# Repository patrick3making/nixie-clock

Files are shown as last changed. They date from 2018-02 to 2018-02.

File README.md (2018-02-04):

# nixie-clock
This alternative clock imitates a nixie tube by edge lighting acrylic tiles. The number on the tile indicates the current hour, and the color aproximately incates the minute.  
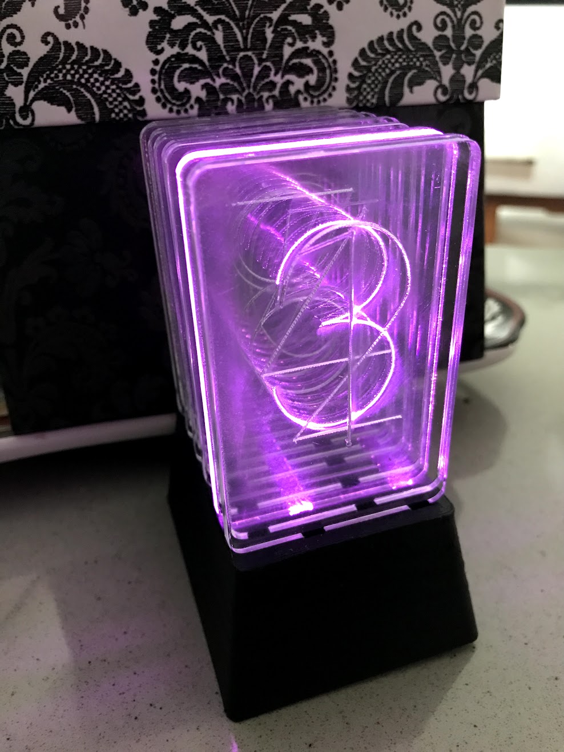
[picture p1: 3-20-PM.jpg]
  
  
## Background  
I have access to a laser cutter at work and I wanted to use it. I searched thingiverse and found [this single led nixie digit ](https://www.thingiverse.com/thing:880429). I modified and laser cut the tiles from that design. The base and circuit assembly is my design.  
  
# Construction
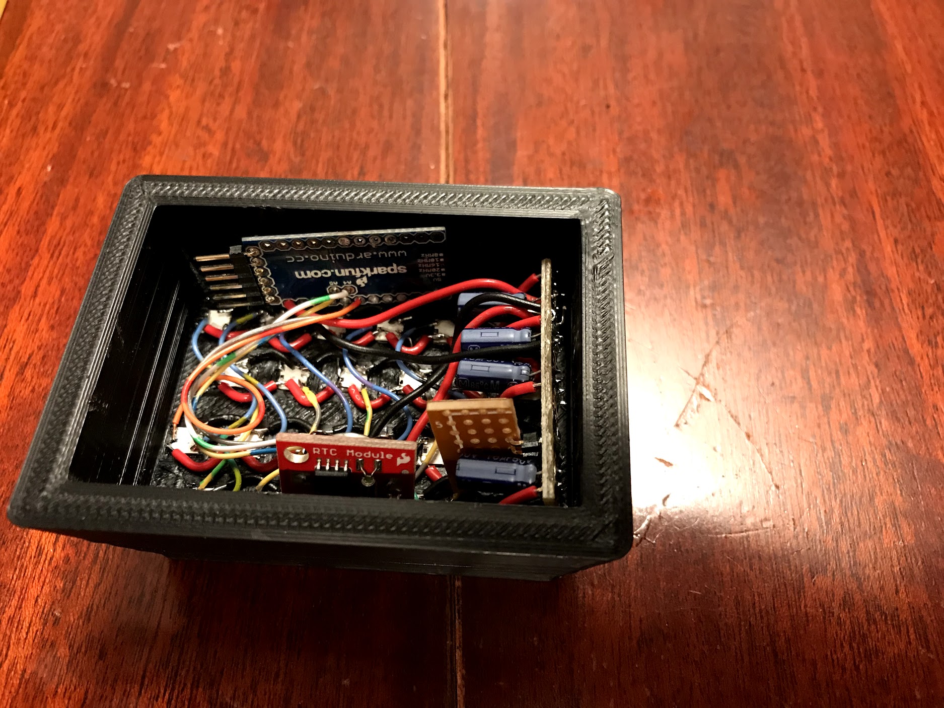
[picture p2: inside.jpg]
  
## Electronics
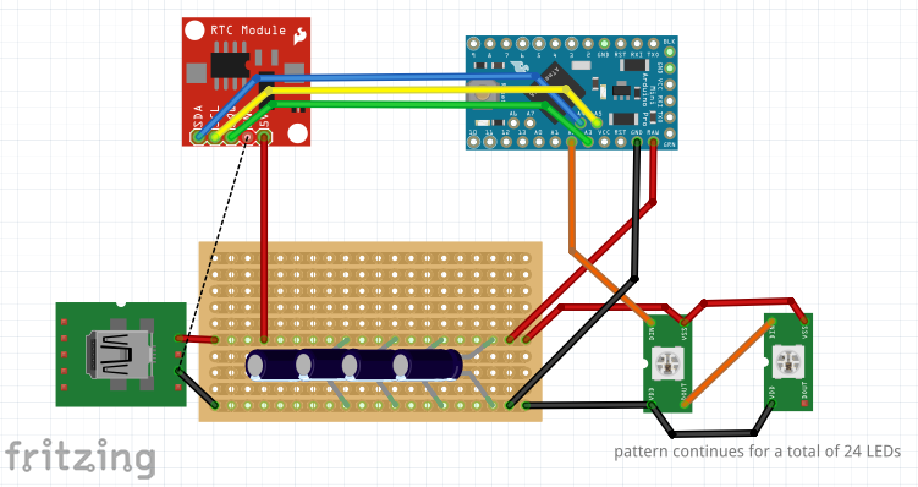
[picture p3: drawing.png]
circuit drawing
  
The electronics are controlled by an [Arduino Pro Mini](https://sfe.i0/p11113). Time is kept by a [SparkFun RTC Module](https://sfe.io/p12708). Light is provided by some [loose WS2812](https://sfe.io/p13667)s. That LED requires some decoupling, so I soldered the power connections together in four rows and added 10uf capacitors at the beginning of each row. It's not ideal, but the seem to work well.  
Power is provided through a USB connector I stole from a broken dev board. Since this runs on 5 volts, USB provides what I need and helps me use up a pile of old cables that might otherwise end up in the trash.  
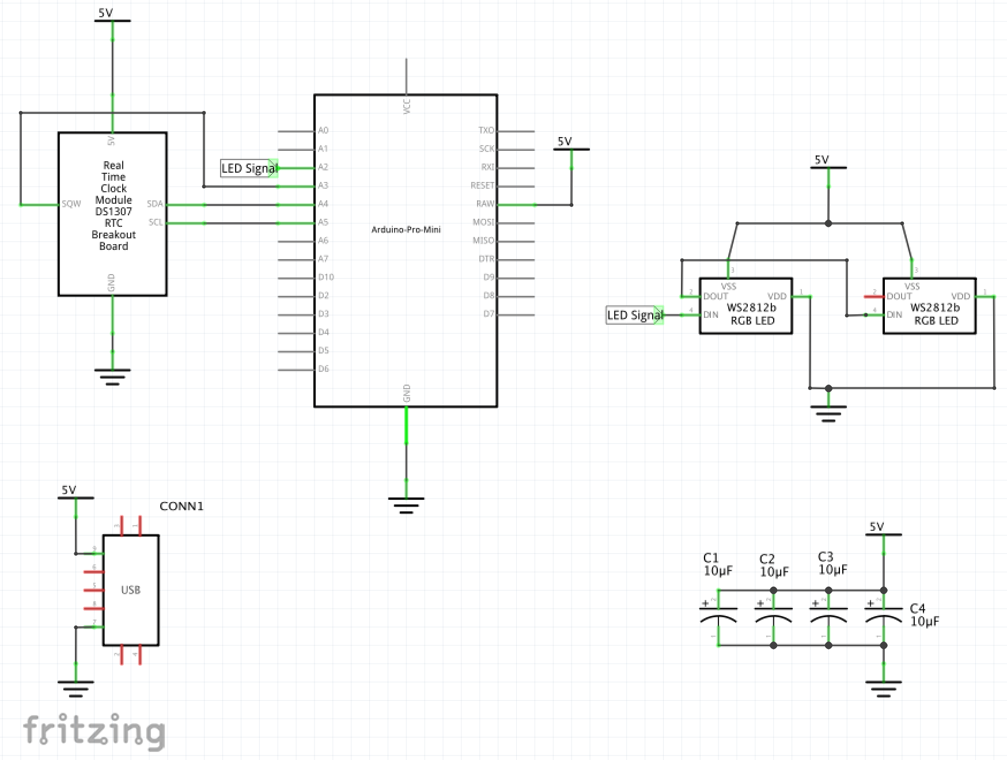
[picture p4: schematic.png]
circuit diagram
  
  
## Base  
The base has holes for the teeth of each tile that fit just right. The array of holes is staggered very close to right, but there is some error from one tile to the next. The space undneath has square holes for the LEDs. The bottom cavity is 1 inch deep because I wanted plenty of room for the electronics.  
  
## Assembly
The best way to do this project is make a custom pcb for the LEDs and controls. In lieu of doing it correctly, I spent immensely greater time and effort putting tiny wires between tiny smd components.  
**Recommendation**: If you make this, redesign the base for [through hole WS2812](https://sfe.io/p12999)s. That will make the soldering easier, and those long leads will save SO MUCH wire stripping.  
After 3D printing the base, I super-glued the LEDs into their sockets. Next I soldered about 100 wires, most of which were less than an inch long. They came from an old 25-pair telephone cable. It makes great hookup wire because it's solid core copper and it's not twisted like cat 5. Power is distributed across a piece of prototyping board.

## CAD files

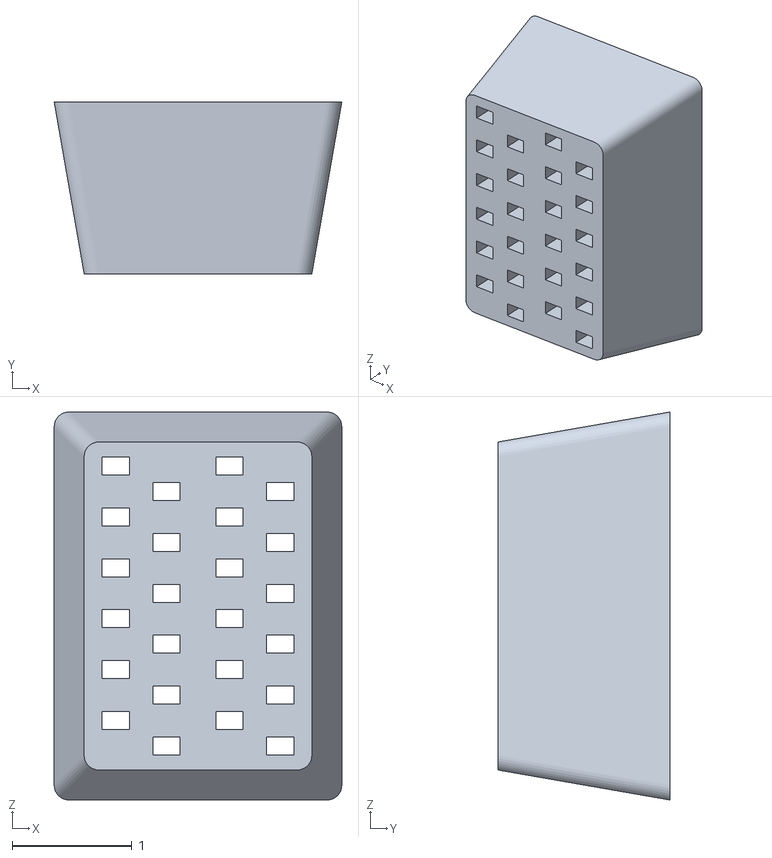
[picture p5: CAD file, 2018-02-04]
nixie_base.stl
2.40 x 1.43 x 3.24

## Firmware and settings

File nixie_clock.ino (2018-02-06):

#include <Adafruit_NeoPixel.h>
#include <SparkFunDS1307RTC.h>
#define DEBUG 1
#define MINIMUM_LUX 15

Adafruit_NeoPixel pixels = Adafruit_NeoPixel(24, A2, NEO_GRB + NEO_KHZ800);

uint8_t numbers[12][2], lastMinute;

void setup() {
  Serial.begin(9600);

  rtc.begin();
  rtc.set24Hour();
#ifdef DEBUG
  rtc.update();
#endif
  pixels.begin();
  pixels.clear();
  pixels.show();
#ifdef DEBUG
  Serial.println("LEDs");
#endif

  for ( uint8_t h = 1; h <= 12; h++ ) {
    numbers[h - 1][0] = 2 * (13 - h) - 2;
    numbers[h - 1][1] = 2 * (13 - h) - 1;
  }

  lastMinute = 70;
  testLights(30);
  Serial.println("Welcome to the Nixie Clock");
  Serial.println("Enter \"?\" to print help message");
  printDate();
}

void loop() {
  rtc.update();
  showTime();
  if (Serial.available()) {
    menuSelect();
  }
  delay(1000);
}

void showTime() {
  int currentMinute = rtc.minute();
  if ( currentMinute != lastMinute) {
#ifdef DEBUG
    printTime();
#endif
    uint8_t currentHour = rtc.hour();
    uint32_t color;
    lastMinute = currentMinute;
    color = minuteToColor(currentMinute);
    if (currentHour > 12) {
      currentHour -= 12;
    }
    showNumber(currentHour, color);
  }
}

void showNumber(uint8_t number, uint32_t color) {
  pixels.clear();
  int pixelNum;
  for ( uint8_t i = 0; i < 2; i++) {
    pixelNum = numbers[number - 1][i];
    pixels.setPixelColor(pixelNum, color);
  }
  pixels.show();
}

uint32_t minuteToColor(byte currentMinute) {
  uint32_t color;
  byte red, green, blue;

  // green
  if ( currentMinute <= 40 ) {
    green = map(currentMinute, 0, 40, 255, MINIMUM_LUX);
  }
  else {
    green = MINIMUM_LUX;
  }

  // red
  if (currentMinute <= 29 ) {
    red = map(currentMinute, 0, 29, MINIMUM_LUX, 255);
  }
  else {
    red = map(currentMinute, 30, 59, 255, MINIMUM_LUX);
  }

  // blue
  if ( currentMinute >= 20 ) {
    blue = map(currentMinute, 20, 59, MINIMUM_LUX, 255);
  }
  else {
    blue = MINIMUM_LUX;
  }

#if DEBUG >= 2
  Serial.print("red: ");
  Serial.println(red);
  Serial.print("green: ");
  Serial.println(green);
  Serial.print("blue: ");
  Serial.println(blue);
#endif

  color = pixels.Color(red, green, blue);
  return color;
}

void testLights(uint8_t dwell) {
  uint8_t number;
  uint32_t color;
  for (int t = 0; t < 60; t++) {
#ifdef DEBUG
    Serial.print("*** T ");
    Serial.println(t);
#endif
    color = minuteToColor(t);
    number = map(t, 0, 59, 1, 12);
    showNumber( number, color);

    delay(dwell);
  }
}

/*
   Menu Commands
*/

void printHelpMessage() {
  printTime();
  Serial.println("");
  Serial.println("Enter \"1\" to set time.");
  Serial.println("Enter \"2\" to set date");
  Serial.println("");
  Serial.println("!!! turn off all line endings !!!");
}

void menuSelect() {
  byte menuSelection = Serial.read();
  switch (menuSelection) {
    case '?':
      printHelpMessage();
      break;
    case '1':
      userSetTime();
      break;
    case '2':
      userSetDate();
      break;
    default:
      Serial.print(menuSelection);
      Serial.println(" is an unknown command");
      printHelpMessage();
      break;
  }
  Serial.println("Enter \"?\" to print help message");
}

void printTime() {
  //get current time
  rtc.update();
  int s = rtc.second();
  int m = rtc.minute();
  int h = rtc.hour();

  //print time
  Serial.println("");
  Serial.print("Current time is: ");
  Serial.print(h);
  Serial.print(":");
  Serial.print(m);
  Serial.print(":");
  Serial.println(s);
}

void printDate() {
  //get current date
  rtc.update();
  int ddd = rtc.day();
  int d = rtc.date();
  int m = rtc.month();
  int y = rtc.year();
  //String dayString = getDayString(ddd);
  String dayString = dayIntToStr[ddd];

  //print date
  Serial.println("");
  Serial.print("Today's date is: ");
  Serial.print(dayString);
  Serial.print(" ");
  Serial.print(y);
  Serial.print("-");
  Serial.print(m);
  Serial.print("-");
  Serial.println(d);
}

void printDayStrings() {
  for (int i = 0; i < 7; i++) {
    Serial.print(i);
    Serial.print(" - ");
    Serial.println(dayIntToStr[i]);
  }
}

void userSetTime() {
  Serial.println("Enter hour (24 hour format):");
  while (!Serial.available()) {
    delay(10);
  }
  int newHour = Serial.parseInt();
  Serial.println("Enter minute:");
  while (!Serial.available()) {
    delay(10);
  }
  int newMinute = Serial.parseInt();
  setRTCTime(newHour, newMinute);
}

void setRTCTime(int hour, int minute) {
  int day = rtc.day();
  int date = rtc.date();
  int month = rtc.month();
  int year = rtc.year();

  rtc.setTime(0, minute, hour, day, date, month, year);
  Serial.println("New time set");
  printTime();
}

void userSetDate() {
  Serial.println("Enter day of the week");
  printDayStrings();
  while (!Serial.available()) {
    delay(10);
  }
  int newDay = Serial.parseInt();

  Serial.println("Enter day of month:");
  while (!Serial.available()) {
    delay(10);
  }
  int newDate = Serial.parseInt();

  Serial.println("Enter month:");
  while (!Serial.available()) {
    delay(10);
  }
  int newMonth = Serial.parseInt();

  Serial.println("Enter year:");
  while (!Serial.available()) {
    delay(10);
  }
  int newYear = Serial.parseInt();

  setRTCDate(newDay, newDate, newMonth, newYear);
  printDate();
}

void setRTCDate(int day, int date, int month, int year) {
  int minute = rtc.minute();
  int hour = rtc.hour();

  rtc.setTime(0, minute, hour, day, date, month, year);
  Serial.println("New date set");
}

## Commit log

2018-02-04 added images
    [nixie-clock.fzz]
2018-02-04 added missing ground wire
    [nixie-clock.fzz]
